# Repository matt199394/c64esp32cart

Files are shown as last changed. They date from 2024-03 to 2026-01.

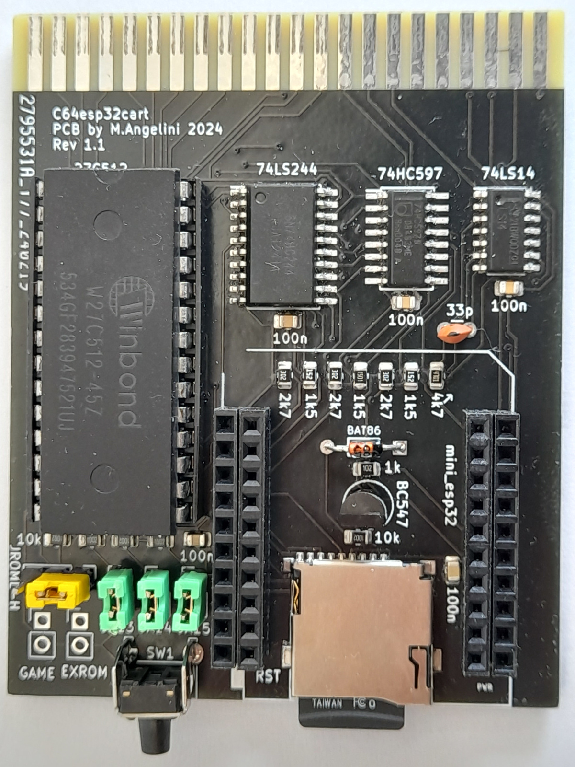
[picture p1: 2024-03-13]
sideUp2.jpg

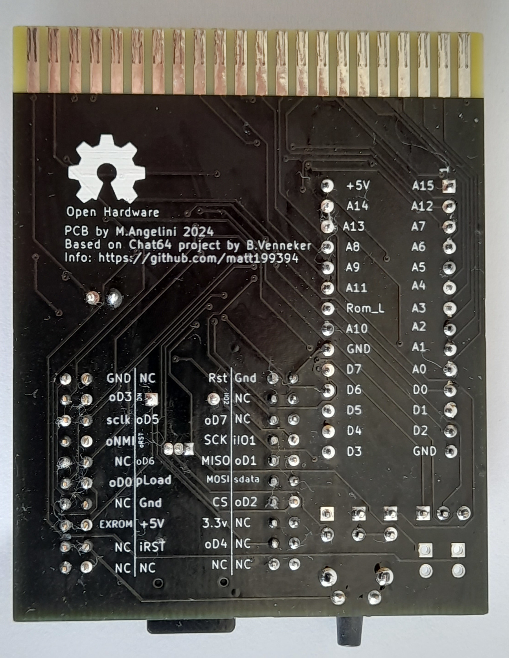
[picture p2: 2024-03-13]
sideBottom.jpg

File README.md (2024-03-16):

Inspired on  chat64 cart by Bart Venneker and Theo van den Beld (https://github.com/bvenneker/Chat64), same hardware with some midifications:
- SD card
- 27C512 EEPROM
- add jumpers to select 8k memory inside EEPROM
- add transistor to control EXROM line
- standart or ultiMax mode jumper
  
 About the code:
  The arduino skeck and ACME assembly code are a working progress, there are many bugs to fix, expecialy SD directory code.
  Not all SIDs file are playable, same as PRG file.
  
Feaures:
- Run PRG file
- play SID files and show SID info
- show koala images
- show current time
- show current weather
- show news by using 2x2 charset

  Video to show the cart in action: https://www.youtube.com/watch?v=Q0KYe2STK2w
  
Any help is appreciate,
Have fun!

Matteo

sideUp1

sideUp2

sideBottom

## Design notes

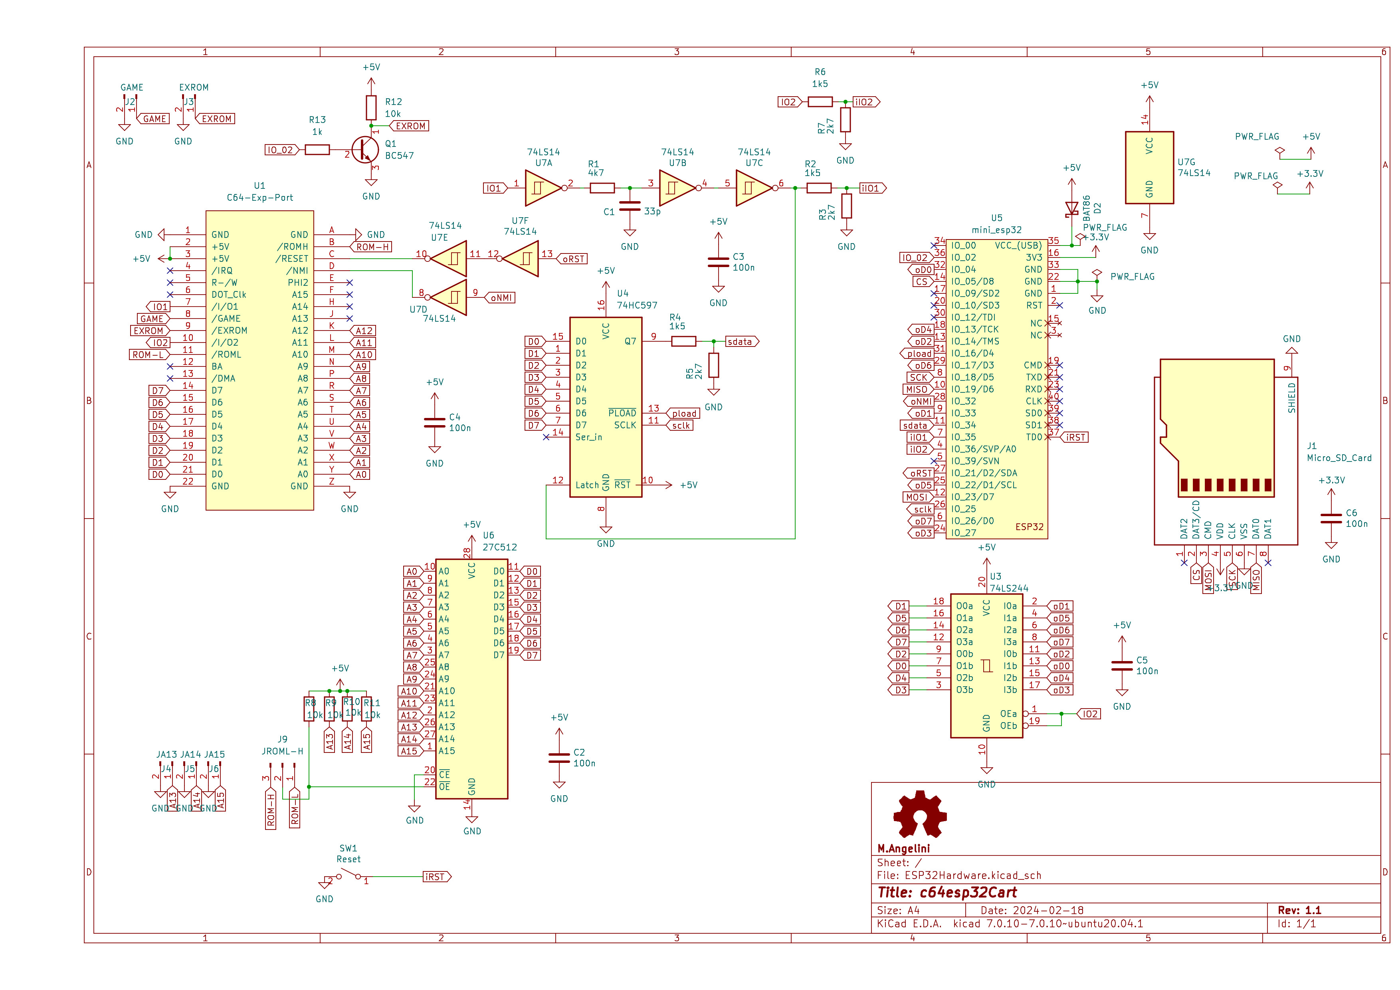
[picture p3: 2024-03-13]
schematic.jpg

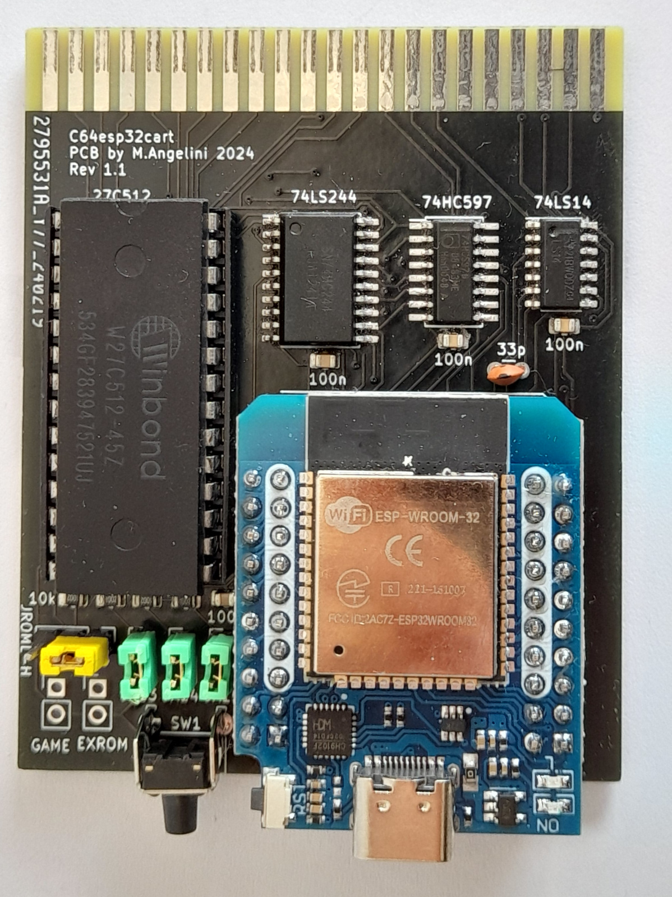
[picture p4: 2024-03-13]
sideUp1.jpg

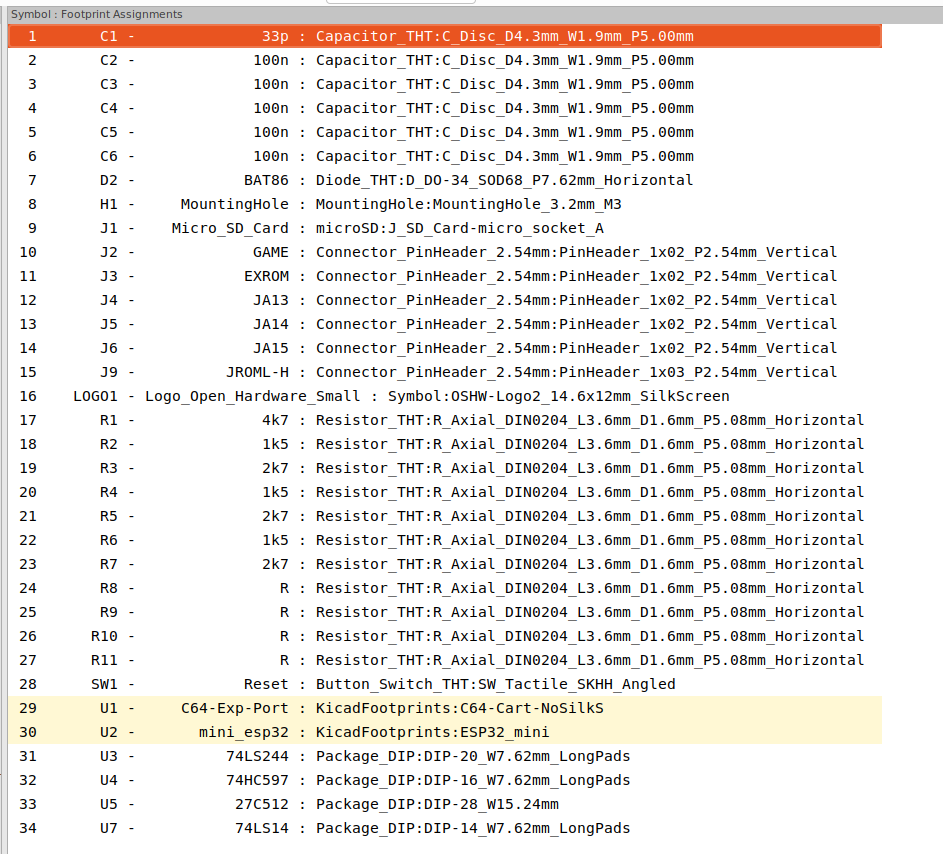
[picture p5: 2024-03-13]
c64esp32crt1.1_kicad7/footprintAssignment.png

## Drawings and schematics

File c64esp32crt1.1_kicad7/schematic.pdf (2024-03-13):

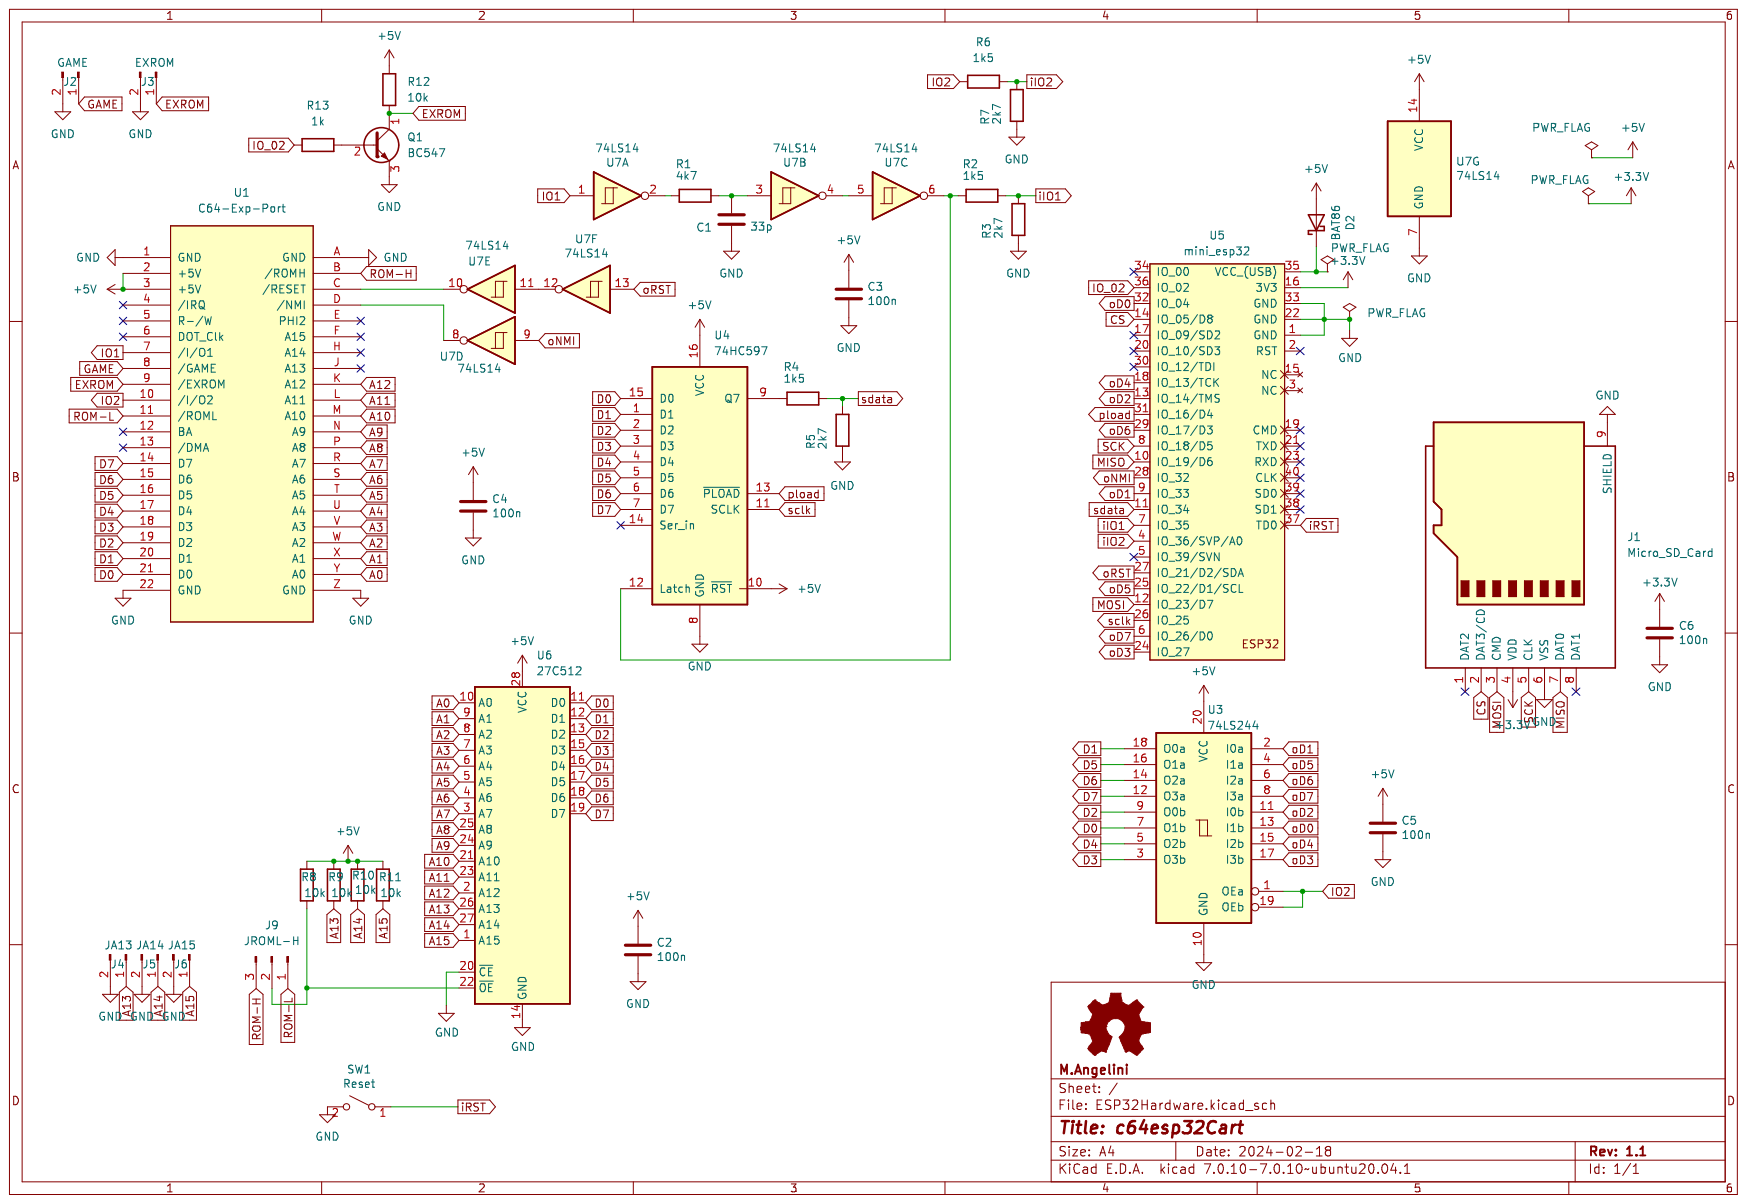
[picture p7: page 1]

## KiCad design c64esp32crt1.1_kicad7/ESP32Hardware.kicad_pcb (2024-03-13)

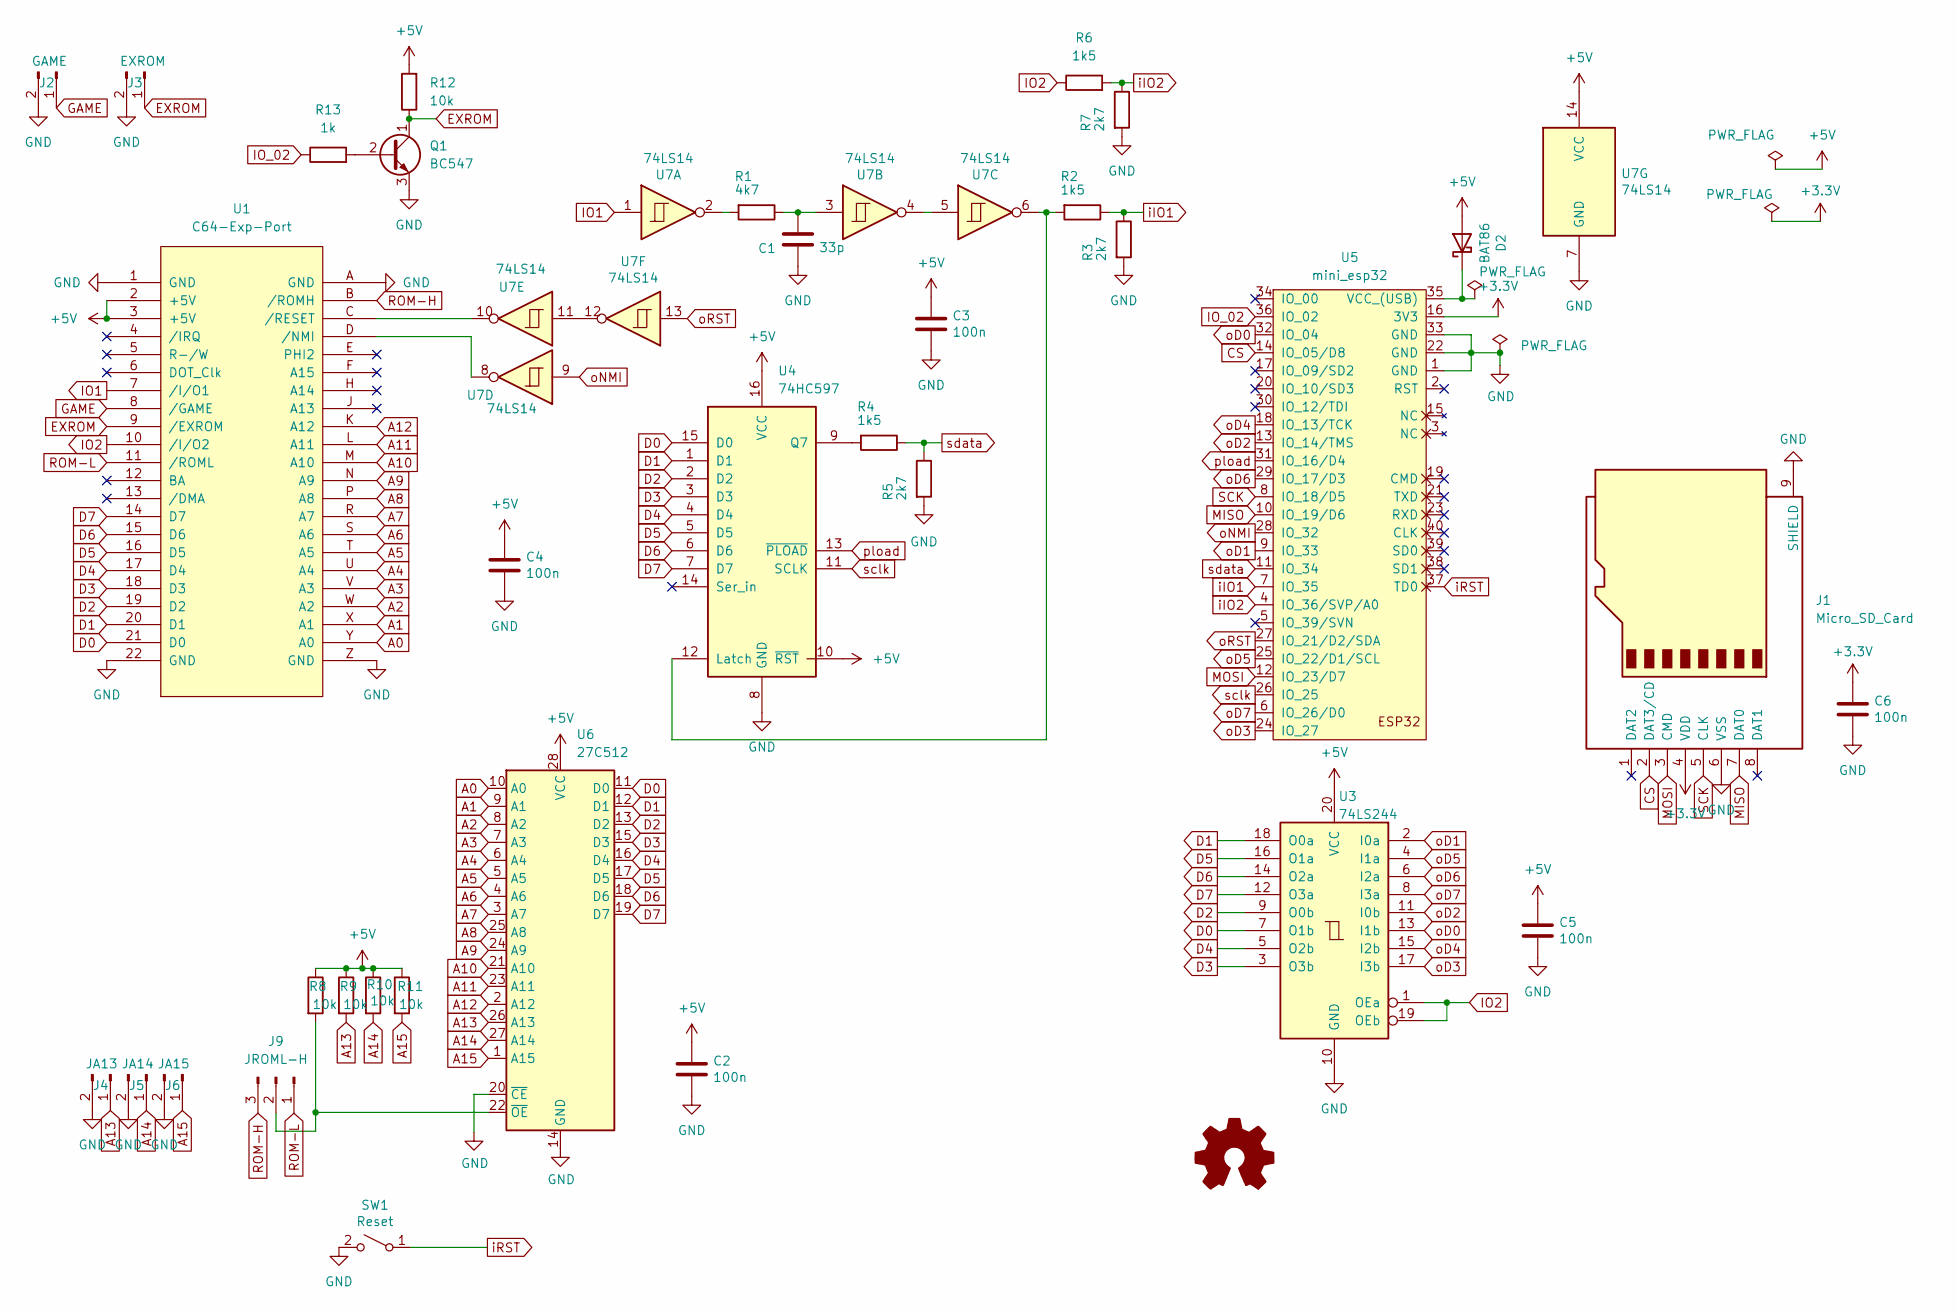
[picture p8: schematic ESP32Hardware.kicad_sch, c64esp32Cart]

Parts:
C1: 33p; C_Disc_D3.0mm_W1.6mm_P2.50mm
C2, C3, C4, C5, C6: 100n; C_0805_2012Metric
D2: BAT86; D_DO-34_SOD68_P7.62mm_Horizontal
J1: Micro_SD_Card; J_SD_Card-micro_socket_A
J2: GAME; PinHeader_1x02_P2.54mm_Vertical
J3: EXROM; PinHeader_1x02_P2.54mm_Vertical
J4: JA13; PinHeader_1x02_P2.54mm_Vertical
J5: JA14; PinHeader_1x02_P2.54mm_Vertical
J6: JA15; PinHeader_1x02_P2.54mm_Vertical
J9: JROML-H; PinHeader_1x03_P2.54mm_Vertical
LOGO1: Logo_Open_Hardware_Small; OSHW-Logo2_14.6x12mm_SilkScreen
Q1: BC547; TO-92_Inline
R1: 4k7; R_0805_2012Metric
R2, R4, R6: 1k5; R_0805_2012Metric
R3, R5, R7: 2k7; R_0805_2012Metric
R8, R9, R10, R11, R12: 10k; R_0805_2012Metric
R13: 1k; R_0805_2012Metric
SW1: Reset; SW_Tactile_SKHH_Angled
U1: C64-Exp-Port; C64-Cart-NoSilkS
U3: 74LS244; SOIC-20W_7.5x12.8mm_P1.27mm
U4: 74HC597; SOIC-16W_5.3x10.2mm_P1.27mm
U5: mini_esp32; ESP32_mini
U6: 27C512; DIP-28_W15.24mm
U7: 74LS14; SOIC-14_3.9x8.7mm_P1.27mm

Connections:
+3.3V: C6.1, J1.4 (VDD), U5.16 (3V3)
+5V: C2.1, C3.1, C4.1, C5.1, D2.2 (A), R8.1, R9.1, R10.1, R11.1, R12.2, U1.2 (+5V), U1.3 (+5V), U3.20 (VCC), U4.10 (~RST), U4.16 (VCC), U6.28 (VCC), U7.14 (VCC)
A0: U1.Y (A0), U6.10 (A0)
A1: U1.X (A1), U6.9 (A1)
A2: U1.W (A2), U6.8 (A2)
A3: U1.V (A3), U6.7 (A3)
A4: U1.U (A4), U6.6 (A4)
A5: U1.T (A5), U6.5 (A5)
A6: U1.S (A6), U6.4 (A6)
A7: U1.R (A7), U6.3 (A7)
A8: U1.P (A8), U6.25 (A8)
A9: U1.N (A9), U6.24 (A9)
A10: U1.M (A10), U6.21 (A10)
A11: U1.L (A11), U6.23 (A11)
A12: U1.K (A12), U6.2 (A12)
A13: J4.1, R9.2, U6.26 (A13)
A14: J5.1, R10.2, U6.27 (A14)
A15: J6.1, R11.2, U6.1 (A15)
CS: J1.2 (DAT3/CD), U5.14 (IO_05/D8)
D0: U1.21 (D0), U3.7 (O1b), U4.15 (D0), U6.11 (D0)
D1: U1.20 (D1), U3.18 (O0a), U4.1 (D1), U6.12 (D1)
D2: U1.19 (D2), U3.9 (O0b), U4.2 (D2), U6.13 (D2)
D3: U1.18 (D3), U3.3 (O3b), U4.3 (D3), U6.15 (D3)
D4: U1.17 (D4), U3.5 (O2b), U4.4 (D4), U6.16 (D4)
D5: U1.16 (D5), U3.16 (O1a), U4.5 (D5), U6.17 (D5)
D6: U1.15 (D6), U3.14 (O2a), U4.6 (D6), U6.18 (D6)
D7: U1.14 (D7), U3.12 (O3a), U4.7 (D7), U6.19 (D7)
EXROM: J3.1, Q1.1 (C), R12.1, U1.9 (/EXROM)
GAME: J2.1, U1.8 (/GAME)
GND: C1.2, C2.2, C3.2, C4.2, C5.2, C6.2, J1.6 (VSS), J1.9 (SHIELD), J2.2, J3.2, J4.2, J5.2, J6.2, Q1.3 (E), R3.2, R5.2, R7.2, SW1.2 (B), U1.1 (GND), U1.22 (GND), U1.A (GND), U1.Z (GND), U3.10 (GND), U4.8 (GND), U5.1 (GND), U5.22 (GND), U5.33 (GND), U6.14 (GND), U6.20 (~CE), U7.7 (GND)
IO1: U1.7 (/I/O1), U7.1
IO2: R6.1, U1.10 (/I/O2), U3.1 (OEa), U3.19 (OEb)
IO_02: R13.1, U5.36 (IO_02)
MISO: J1.7 (DAT0), U5.10 (IO_19/D6)
MOSI: J1.3 (CMD), U5.12 (IO_23/D7)
unnamed: C1.1, R1.1, U7.3
unnamed: D2.1 (K), U5.35 (VCC_(USB))
unnamed: J9.2, R8.2, U6.22 (~OE)
unnamed: Q1.2 (B), R13.2
unnamed: R1.2, U7.2
unnamed: U1.D (/NMI), U7.8
unnamed: U1.C (/RESET), U7.10
unnamed: R2.2, U4.12 (Latch), U7.6
unnamed: R4.2, U4.9 (Q7)
unnamed: U7.4, U7.5
unnamed: U7.11, U7.12
ROM-H: J9.3, U1.B (/ROMH)
ROM-L: J9.1, U1.11 (/ROML)
SCK: J1.5 (CLK), U5.8 (IO_18/D5)
iIO1: R2.1, R3.1, U5.7 (IO_35)
iIO2: R6.2, R7.1, U5.4 (IO_36/SVP/A0)
iRST: SW1.1 (A), U5.37 (TD0)
oD0: U3.13 (I1b), U5.32 (IO_04)
oD1: U3.2 (I0a), U5.9 (IO_33)
oD2: U3.11 (I0b), U5.13 (IO_14/TMS)
oD3: U3.17 (I3b), U5.24 (IO_27)
oD4: U3.15 (I2b), U5.18 (IO_13/TCK)
oD5: U3.4 (I1a), U5.25 (IO_22/D1/SCL)
oD6: U3.6 (I2a), U5.29 (IO_17/D3)
oD7: U3.8 (I3a), U5.6 (IO_26/D0)
oNMI: U5.28 (IO_32), U7.9
oRST: U5.27 (IO_21/D2/SDA), U7.13
pload: U4.13 (~PLOAD), U5.31 (IO_16/D4)
sclk: U4.11 (SCLK), U5.26 (IO_25)
sdata: R4.1, R5.1, U5.11 (IO_34)

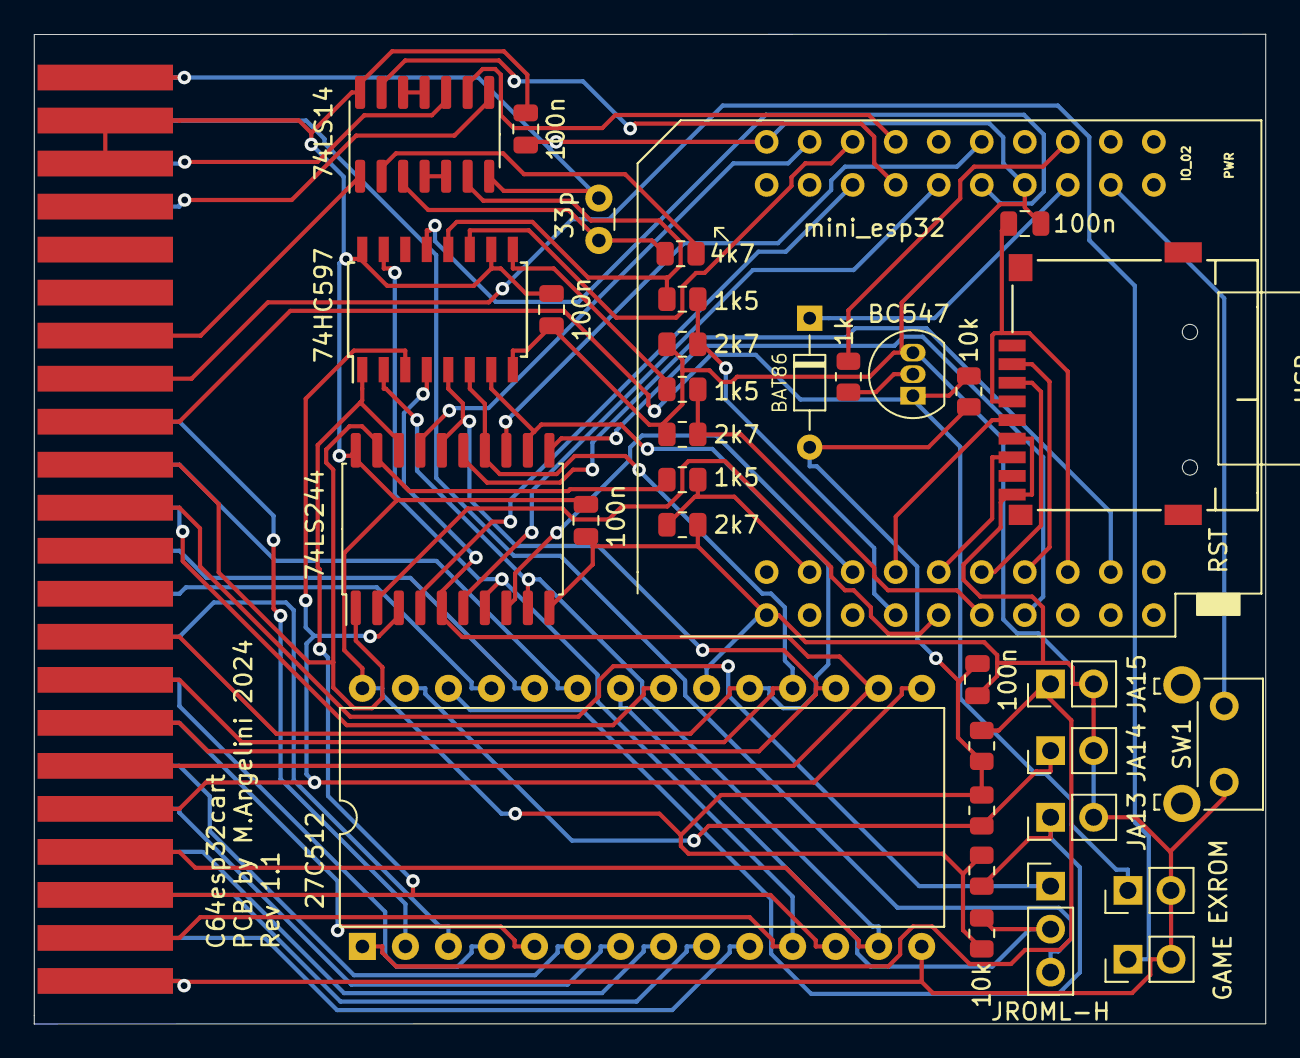
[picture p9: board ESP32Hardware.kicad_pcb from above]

Board: 2 copper layers, 72.7 x 58.4 mm, 36 parts (0 on the bottom side), 65 nets.

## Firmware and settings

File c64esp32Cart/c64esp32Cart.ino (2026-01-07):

/*
 * Inspired on  chat64 cart by Bart Venneker and Theo van den Beld, same hardware with some midifications:
 * - SD card
 * - 27C512 EEPROM
 * - add jumpers to select 8k memory inside EEPROM
 * - add transistor to control EXROM line
 * - standart or ultiMax mode jumper
 * 
 * About the skech:
 * The sketck is a working progress, there are many bugs to fix, expecialy SD directory code.
 * Not all SIDs file are playable, same as PRG file.
 * Feaures:
 * - Run PRG file
 * - play SID files and show SID info
 * - show koala images
 * - show current time
 * - show current weather
 * - show news by using 2x2 charset
 * 
 * Any help is appreciate,
 * Have fun
 * 
 * M.Angelini
 *
*/
#include <WiFi.h>
#include <NTPClient.h>
#include <HTTPClient.h>
#include <WiFiUdp.h>
#include <ArduinoJson.h>

#include <SPI.h>
#include <SD.h>
//#include "BluetoothSerial.h"
#include "supermon.h"
#include "chars.h"
//#include "SID.h"


const char *ssid     = "xxxx";
const char *password = "xxxx";

//forecast API http://api.openweathermap.org

String URL = "http://api.openweathermap.org/data/2.5/weather?";
String openweatherApiKey = "xxxx";
// Replace with your location Credentials
String lat = "43.06071239857755";
String lon = "10.614730891178944";

//news API: https://newsapi.org

String newsApiKey = "xxxxx";

WiFiUDP ntpUDP;
NTPClient timeClient(ntpUDP, "pool.ntp.org");

File directory;
File myFile;
File root;

//BluetoothSerial SerialBT;

// ********************************
// **     Global Variables       **
// ********************************

bool invert_Reset = true;  


String weekDays[7]={"Sunday", "monday", "tuesday", "wednesday", "thursday", "friday", "saturday"};
String months[12]={"january", "february", "march", "april", "may", "june", "july", "august", "september", "october", "november", "december"};
              

volatile bool dataFromC64 = false;
volatile bool io2 = false;
unsigned long outbuffersize = 0;

volatile byte ch = 0;
int num;

char inbuffer[250];  // a character buffer for incomming data
int inbuffersize = 0;
char *outbuffer;

String currentDate;
String weatherMain = "";
String weatherDescription = "";
String weatherLocation = "";
String country;
int humidity;
int pressure;
float temp;
float tempMin, tempMax;
int clouds;
float windSpeed;
String weatherString = "";

uint32_t SID_data_size = 0;
uint16_t MagicID = 0;
uint16_t VERSION = 0;
bool PLAYABLE_SID = false;

uint32_t IRQ_TYPE_PER_TUNE = 0; // subtune speed info
uint32_t VIDEO_TYPE = 0; // pal or ntsc
uint32_t MODEL_TYPE = 0; //MOS6581 or MOS8580
uint32_t FLAGS76 = 0;
uint8_t ComputeMUSplayer = 0;
uint8_t C64Compatible = 0;
uint16_t LOAD_ADDRESS = 0;
uint32_t SUBTUNE_SPEED = 0;
char info_string_SID [300];

uint16_t SID_load_start = 0; //SID_data[0x7c] + (SID_data[0x7d] * 256); // get start address from .sid file
uint16_t SID_load_end = 0; //SID_start + SID_data_size - 0x7e ; // end address of music routine , not included "busy blocks", aka, ram needed after end of actual sid file.

uint16_t SID_play = 0;//SID_data[13] + (SID_data[12] * 256); // sid play address
uint16_t SID_init = 0;//SID_data[11] + (SID_data[10] * 256); // sid init address

uint8_t SID_default_tune = 0;//SID_data[17] + (SID_data[16] * 256); // default song to be played first
uint8_t SID_number_of_tunes = 0;//SID_data[15] + (SID_data[14] * 256); // number of tunes in sid
uint8_t SID_current_tune = 0;//SID_default_tune;

char SID_filename[128] ; // reserve 128 bytes for file name
char SID_DIR_name [128] ; // reserve 128 bytes for directory path name
char SID_path_filename [256] ; // reserve 256 bytes for full path of file
bool IS_SID_FILE = false; //  for extension check

char  SIDinfo_filetype [8] ;
char  SIDinfo_name [33] ;
char  SIDinfo_author [33] ;
char  SIDinfo_released [33] ;
char  SIDinfo_VIDEO [14] ;
char  SIDinfo_CLOCK [7] ;
char  SIDinfo_PLAYABLE [6];
char  SIDinfo_MODEL [20];
char  SIDinfo_PLAYLIST [10];
char  SIDinfo_RANDOM [4];
char  SIDheader [0x7e];

String hex_value = "";

String response = "";
char title [2048];
String currentDir = "";
String parentDir = "";

// ********************************
// **        OUTPUTS             **
// ********************************
// see http://www.bartvenneker.nl/index.php?art=0030
// for usable io pins!
#define oC64D0 GPIO_NUM_4   // data bit 0 for data from the ESP32 to the C64
#define oC64D1 GPIO_NUM_33  // data bit 1 for data from the ESP32 to the C64
#define oC64D2 GPIO_NUM_14  // data bit 2 for data from the ESP32 to the C64
#define oC64D3 GPIO_NUM_27  // data bit 3 for data from the ESP32 to the C64
#define oC64D4 GPIO_NUM_13  // data bit 4 for data from the ESP32 to the C64
#define oC64D5 GPIO_NUM_22  // data bit 5 for data from the ESP32 to the C64
#define oC64D6 GPIO_NUM_17  // data bit 6 for data from the ESP32 to the C64
#define oC64D7 GPIO_NUM_26  // data bit 7 for data from the ESP32 to the C64

#define oC64RST GPIO_NUM_21  // reset signal to C64
#define oC64NMI GPIO_NUM_32  // non-maskable interrupt signal to C64
 #define CLED GPIO_NUM_2      // led on ESP32 module
#define sclk GPIO_NUM_25     // serial clock signal to the shift register
#define pload GPIO_NUM_16    // parallel load signal to the shift register

// ********************************
// **        INPUTS             **
// ********************************
#define resetSwitch GPIO_NUM_15  // this pin outputs PWM signal at boot
#define C64IO1 GPIO_NUM_35
#define sdata GPIO_NUM_34
#define C64IO2 GPIO_NUM_36

// ********************************
// **        SD connections      **
// ********************************
/*
 
  MOSI - pin 23
  MISO - pin 19
  SCK - pin 18
  CS - GPIO_NUM_5 
*/

#define CS GPIO_NUM_5

// *************************************************
// Interrupt routine for IO1
// *************************************************
void IRAM_ATTR isr_io1() {

  // This signal goes LOW when the commodore writes to (or reads from) the IO1 address space
  // In our case the Commodore 64 only WRITES the IO1 address space, so ESP32 can read the data.
  digitalWrite(oC64D7, LOW);  // this pin is used for flow controll,
                              // make it low so the C64 will not send the next byte
                              // until we are ready for it
  ch = 0;
  digitalWrite(pload, HIGH);  // stop loading parallel data and enable shifting serial data
  ch = shiftIn(sdata, sclk, MSBFIRST);
  dataFromC64 = true;
  digitalWrite(pload, LOW);
}

// *************************************************
// Interrupt routine for IO2
// *************************************************
void IRAM_ATTR isr_io2() {
  // This signal goes LOW when the commodore reads from (or write to) the IO2 address space
  // In this case the commodore only uses the IO2 address space to read from, so ESP32 can send data.
  io2 = true;
}

// *************************************************
// Interrupt routine, to restart the esp32
// *************************************************
void IRAM_ATTR isr_reset() {
  ESP.restart();
}

// ******************************************************************************
// send a single byte to the C64
// ******************************************************************************
void sendByte(byte b) {
  outByte(b);
  io2 = false;
  triggerNMI();
  // wait for io2 interupt
  while (io2 == false) {
    delayMicroseconds(10); //default 2
  }
  io2 = false;
}

// ******************************************************************************
// void to set a byte in the 74ls244 buffer
// ******************************************************************************
void outByte(byte c) {
  gpio_set_level(oC64D0, bool(c & B00000001));
  gpio_set_level(oC64D1, bool(c & B00000010));
  gpio_set_level(oC64D2, bool(c & B00000100));
  gpio_set_level(oC64D3, bool(c & B00001000));
  gpio_set_level(oC64D4, bool(c & B00010000));
  gpio_set_level(oC64D5, bool(c & B00100000));
  gpio_set_level(oC64D6, bool(c & B01000000));
  gpio_set_level(oC64D7, bool(c & B10000000));
}

// ******************************************************************************
// pull the NMI line low for a few microseconds
// ******************************************************************************
void triggerNMI() {
  digitalWrite(oC64NMI, HIGH);
  delayMicroseconds(150);  // minimal 100 microseconds delay default 125
  digitalWrite(oC64NMI, LOW);
}


void writeDirectoryFile (File folder) {

   
  directory = SD.open("/directory.txt", FILE_WRITE);

  if (folder) {
    directory.println("/..");
    
  while (true) {
    File entry =  folder.openNextFile();
    if (! entry) {
      // no more files
      entry.close();
      break;
    }

      
    if (entry.isDirectory()) {
        directory.print("/");
        directory.println(entry.name());
        
        
      }
    else {  
		directory.println(entry.name());
    }		
    }
    
 
  directory.close();
  
  }
  else {
    Serial.println("error opening folder");  
}

myFile = SD.open("/directory.txt");

  if (myFile) {

    Serial.println("directory:");
    while (myFile.available()) {
    Serial.write(myFile.read());
    }
    myFile.close();

  } else {
    Serial.println("error opening directory.txt file");
  }
}

void getTime(){
  timeClient.begin();
  // Set offset time in seconds to adjust for your timezone, for example:
  // GMT +1 = 3600
  // GMT +8 = 28800
  // GMT -1 = -3600
  // GMT 0 = 0
  timeClient.setTimeOffset(3600);

  timeClient.update();

  time_t epochTime = timeClient.getEpochTime();
  String formattedTime = timeClient.getFormattedTime();
 
  int currentHour = timeClient.getHours();
  int currentMinute = timeClient.getMinutes();
  int currentSecond = timeClient.getSeconds();
  String weekDay = weekDays[timeClient.getDay()];
     
  //Get a time structure
  struct tm *ptm = gmtime ((time_t *)&epochTime); 
  int monthDay = ptm->tm_mday;
  int currentMonth = ptm->tm_mon+1;
  String currentMonthName = months[currentMonth-1];
  int currentYear = ptm->tm_year+1900;
  
  //Print complete date:
  currentDate = "Time: " + formattedTime + "\r\n" + "Date: " + weekDay + " " + String(monthDay) + " " + currentMonthName + " " + String(currentYear)+ "\r\n";
  }


void getWeatherData(){
    HTTPClient http;

    //Set HTTP Request Final URL with Location and API key information
    http.begin(URL + "lat=" + lat + "&lon=" + lon + "&units=metric&appid=" + openweatherApiKey);

    // start connection and send HTTP Request
    int httpCode = http.GET();

    // httpCode will be negative on error
    if (httpCode > 0) {

      //Read Data as a JSON string
      String JSON_Data = http.getString();
      //Serial.println(JSON_Data);

      //Retrieve some information about the weather from the JSON format
      DynamicJsonDocument doc(2048);
      deserializeJson(doc, JSON_Data);
      JsonObject obj = doc.as<JsonObject>();
/*
      //Display the Current Weather Info
      const char* description = obj["weather"][0]["description"].as<const char*>();
      const float temp = obj["main"]["temp"].as<float>();
      const float humidity = obj["main"]["humidity"].as<float>();
*/
      //weatherMain = obj["weather"]["main"].as<String>();
      weatherDescription = obj["weather"][0]["description"].as<String>();
      //weatherDescription.toLowerCase();
      weatherLocation = obj["name"].as<String>();
      //weatherLocation.toLowerCase();
      country = obj["sys"]["country"].as<String>();
      //country.toLowerCase();
      temp = obj["main"]["temp"];
      humidity = obj["main"]["humidity"];
      pressure = obj["main"]["pressure"];
      tempMin = obj["main"]["temp_min"];
      tempMax = obj["main"]["temp_max"];
      windSpeed = obj["wind"]["speed"];
      clouds = obj["Clouds"]["all"];
      weatherString = "Location: " + weatherLocation + "," + country + "\r\n";
      weatherString += "Description: " + weatherDescription + "\r\n";
      weatherString += "Temp: " + String(temp,1) + "c (" + String(tempMin,1) + "-" + String(tempMax,1) + ")  "+ "\r\n" ;
      weatherString += "Humidity: " + String(humidity) + "%  "+ "\r\n";
      weatherString += "Pressure: " + String(pressure) + " hpa  "+ "\r\n";
      weatherString += "Clouds: " + String(clouds) + "%  "+ "\r\n";
      weatherString += "Wind: " + String(windSpeed,1) + " m/s"+ "\r\n";
      
      //Serial.print(weatherString);

    } else {
      Serial.println("Error!");
      Serial.print("Can't Get DATA!");
    }

    http.end();
}

// ******************************************************************************
// translate screen codes to ascii
// ******************************************************************************
char screenCode_to_Ascii(byte screenCode) {

  byte screentoascii[] = { 64, 97, 98, 99, 100, 101, 102, 103, 104, 105,
                           106, 107, 108, 109, 110, 111, 112, 113, 114, 115,
                           116, 117, 118, 119, 120, 121, 122, 91, 92, 93,
                           94, 95, 32, 33, 34, 125, 36, 37, 38, 39,
                           40, 41, 42, 43, 44, 45, 46, 47, 48, 49,
                           50, 51, 52, 53, 54, 55, 56, 57, 58, 59,
                           60, 61, 62, 63, 95, 65, 66, 67, 68, 69,
                           70, 71, 72, 73, 74, 75, 76, 77, 78, 79,
                           80, 81, 82, 83, 84, 85, 86, 87, 88, 89,
                           90, 43, 32, 124, 32, 32, 32, 32, 32, 32,
                           95, 32, 32, 32, 32, 32, 32, 32, 32, 32,
                           32, 95, 32, 32, 32, 32, 32, 32, 32, 32,
                           32, 32, 32, 32, 32, 32, 32, 32, 32 };

  char result = char(screenCode);
  if (screenCode < 129) result = char(screentoascii[screenCode]);
  return result;
}
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
void loop() {

    gpio_set_level(oC64D7, HIGH);
    
    if (dataFromC64){
    dataFromC64 = false;
    gpio_set_level(oC64D7, LOW);  // flow control

    // 49 = read directory from SD
    // 50 = load supermon+
    // 51 = receive string in inbuffer[i]
    // 52 = Get time & weather
    // 53 = file from ESP32 to c64
    

    switch (ch) { 
      //========================================================
      case 49:{           // 49 = read directory from SD

             File dataFile = SD.open("/directory.txt");
        
      if (dataFile) {
      outbuffersize = dataFile.size();
      sendByte((byte)(outbuffersize));
      sendByte((byte)(outbuffersize>>8)); 
      sendByte(0x00);
      sendByte(0x10);
 
     for (int x = 0; x < outbuffersize; x++) {
          sendByte(asciiToPET(dataFile.read()));}
    dataFile.close();}
    
     else {
     Serial.println("error opening directory.txt");}
     break;}
     
   //========================================================         
      case 50:{         // 50 = load supermon+
          

          outbuffersize = 2820; 
          sendByte((byte)(outbuffersize));
          sendByte((byte)(outbuffersize>>8));
          for (int x = 0; x < outbuffersize; x++) {
          sendByte(supermonA000[x]);}
          
      break;}
   
      
    //========================================================
      case 51:{         // 51 = receive string in inbuffer[i] 
   
  int i = 0;

  while (ch != 128) {
    gpio_set_level(oC64D7, HIGH);  // ready for next byte
    while (dataFromC64 == false) {
      delayMicroseconds(2);  // wait for next byte
    }
    gpio_set_level(oC64D7, LOW);  //
    dataFromC64 = false;
    inbuffer[i] = screenCode_to_Ascii(ch);
    i++;
  }
  i--;
  inbuffer[i] = 0;  // close the buffer
  inbuffersize = i;

  if (strcmp(&inbuffer[strlen(inbuffer) - 4], ".SID") == 0) {
    IS_SID_FILE = true;
  }
   if (strcmp(&inbuffer[strlen(inbuffer) - 4], ".sid") == 0) {
    IS_SID_FILE = true;
  }
  else IS_SID_FILE = false;
  if (IS_SID_FILE) Serial.println("SID file ok");
   else Serial.println("Not SID file");
  // char bns[inbuffersize];
  // strncpy ( bns, inbuffer, inbuffersize + 1);
  String text_lowcase = inbuffer;
  //text_lowcase.toLowerCase();
  Serial.println(text_lowcase);
  
     break;}
     
     //========================================================
     case 52:{   //52 = Get time & weather

    getTime();
    getWeatherData();
    currentDate += weatherString;

  Serial.println(currentDate);
   
    outbuffersize = currentDate.length();
  
    sendByte((byte)(outbuffersize));
    sendByte((byte)(outbuffersize>>8));
    sendByte(0x00);
    sendByte(0x10); 
    
    for (int x = 0; x < outbuffersize; x++) {
          sendByte(asciiToPET(currentDate[x]));}
    
     break;}

    //========================================================
      case 53:{          // 53 = file from ESP32 to c64
      
      String fileName = currentDir;
      bool result = strcmp(inbuffer,"/..");
      
    if (result == 0){
      currentDir = parentDir; 
      File dir;
       
     dir = SD.open(currentDir);
         writeDirectoryFile (dir);

         
         dir.close(); 
    }

    
	  else if (inbuffer[0] == '/'){

     currentDir = inbuffer;
     
		 File dir;
       
		 dir = SD.open(currentDir);
         writeDirectoryFile (dir);

         
         dir.close(); 
	  }
	  
	  else {
        fileName += "/";
        fileName += inbuffer;
		  
        File dataFile = SD.open(fileName);
  
  
          
  if (dataFile) {
    
  
    if (IS_SID_FILE == false){
    outbuffersize = dataFile.size();
    sendByte((byte)(outbuffersize));
    sendByte((byte)(outbuffersize>>8)); 
    
    for (int x = 0; x < outbuffersize; x++) {
          sendByte(dataFile.read());}
    dataFile.close();
    Serial.print("Load: ");
    Serial.println(inbuffer);}

    else{
    for (int i = 0; i < 0x7c; i++) {
              SIDheader[i] = dataFile.read();
          }

    SID_data_size = dataFile.size() - 0x7c;
    outbuffersize = SID_data_size;

    
    outbuffer = (char*)malloc(outbuffersize);
    
    if (outbuffer == NULL) {
      Serial.println("errore memoria!");
    }

    for (int i = 0; i < outbuffersize; i++) {
              outbuffer[i] = dataFile.read();
          }

 
            PLAYABLE_SID = Compatibility_check();
            infoSID();
            
          sendByte((byte)(5));
          sendByte((byte)(0)); 
          sendByte(0x3c);    //cassette_buffer    
          sendByte(0x03);

          sendByte((byte)(IS_SID_FILE));
          sendByte((byte)(SID_init));
          sendByte((byte)(SID_init>>8));
          sendByte((byte)(SID_play));
          sendByte((byte)(SID_play>>8));

          
          
          dataFile.close();       
  }
  }
  
    
  else {
    Serial.print("error opening ");
    Serial.println(fileName);}
  
	  }
      break;}

   //========================================================
     case 55:{   //55 = send SID file to c64
    
   
    
    sendByte((byte)(SID_data_size));
    sendByte((byte)(SID_data_size>>8)); 

    
    for (int x = 0; x < SID_data_size; x++) {
          sendByte(outbuffer[x]);}
          
    free(outbuffer);
   
     break;}
    //========================================================
     case 56:{   //56 = print SID info

    outbuffersize = strlen(info_string_SID);
  
    sendByte((byte)(outbuffersize));
    sendByte((byte)(outbuffersize>>8));
    sendByte(0x00);
    sendByte(0x10);

    String text_lowcase = info_string_SID;
    //text_lowcase.toLowerCase();
    
    for (int x = 0; x < outbuffersize; x++) {
          sendByte(asciiToPET(text_lowcase[x]));}
    
     break;}

     //========================================================         
      case 57:{         // 57 = load charset 1x2
          

          outbuffersize = 2048; 
          sendByte((byte)(outbuffersize));
          sendByte((byte)(outbuffersize>>8));
          sendByte(0x00);
          sendByte(0x38);
          for (int x = 0; x < outbuffersize; x++) {
          sendByte(chars[x]);}
          
      break;}

      //======================================================== 
      case 58:{       // 57 = get NEWS
        
      HTTPClient http;
      http.begin("https://newsapi.org/v2/top-headlines?country=it&apiKey=" + newsApiKey);
      int httpCode = http.GET();
      response = http.getString();

      // Parse the response to get the headlines
     DynamicJsonDocument doc(19508);
     //DeserializationError error = deserializeJson(doc, payload);
     DeserializationError error = deserializeJson(doc, response);
     if (error) {
     Serial.println("Error parsing news data");
     return;
     }

     // Extract the "title" field from the first article
    JsonArray articles = doc["articles"];

    //String title = articles[0]["title"];
    // Display the title of each article

    strcpy(title, "");
    for (int i = 0; i < articles.size(); i++) {
  
    strcat(title, articles[i]["title"]);
    strcat(title, " ");
 
   }

   Serial.println(title);
 
   String text_lowcase = title;
   text_lowcase.toLowerCase();
   outbuffersize = text_lowcase.length();
  
    sendByte((byte)(outbuffersize));
    sendByte((byte)(outbuffersize>>8));
    sendByte(0x00);
    sendByte(0x30); 
    
    for (int x = 0; x < outbuffersize; x++) {
          sendByte(Ascii_to_screenCode(text_lowcase[x]));}
    sendByte(0xff);

    http.end();
   }

    //========================================================
    //========================================================
    }
    }    
}  // end of main loop
